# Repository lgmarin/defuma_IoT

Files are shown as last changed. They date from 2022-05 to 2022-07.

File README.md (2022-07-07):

# Defuma IoT

## _An ESP8266 based smoker controller and data acquisition system. AKA: Defumadeira Controle Remoto_

[]()


<p align="center">
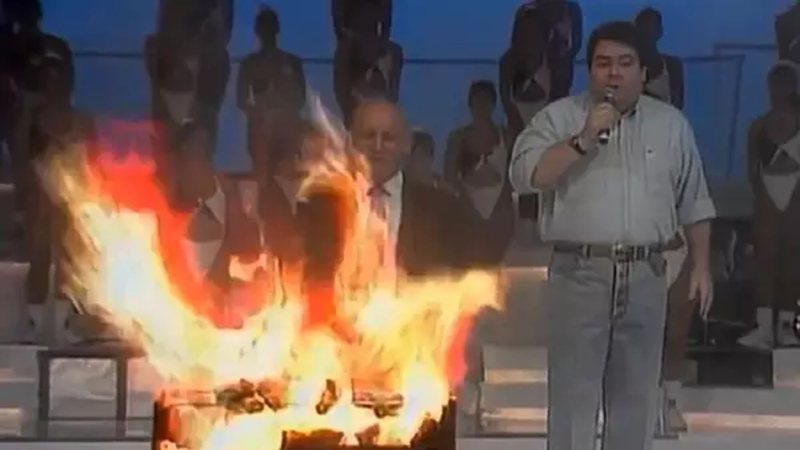
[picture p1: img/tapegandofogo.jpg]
Tá pegando fogo BIXO!!!!
  
</p>

This project was developed with the intention to help to produce a delicious, tender and with an amazing smoked flavored meat! What better way than to make a Nerd happy than with some long smoking process with some friends, some beer and some technology involved, why not?

To acquire a good quality smoked meat, the amount of smoke produced, and mainly the temperature should be constantly controlled (temperature should not be too low and specially, not too high) during the long 12 hours (or more, depending on the cut) to succeed.

The idea here is to have a controller that will display the smoker temperature with a buzzer to signalize the low and high temperature drops. The base system will be developed using an ESP8266 board, that allows for a Wifi Access Point connection that will expose a Web Server that will also display the temperature and allow to define the temperature thresholds.

## Objectives

Development of a data monitoring for a meat smoker:

* Inclusion of a Display and Buzzer to notify the user
* Allow for WiFi connection to visualize the data using a smartphone
* Simple construction and low power
* Future upgrades may include a servo to control the air intake (thus, controlling the smoker temperature)

## Peripherals

* NodeMCU V1.2 ESP8266 Development Board
    * The final project will be built using a ESP12F board.
* MAX6675 Type K Thermocouple Module
* TM1637 4 Digit 8 Segment Display
* Passive Buzzer

## Schematics and List of Materials

<p align="center">
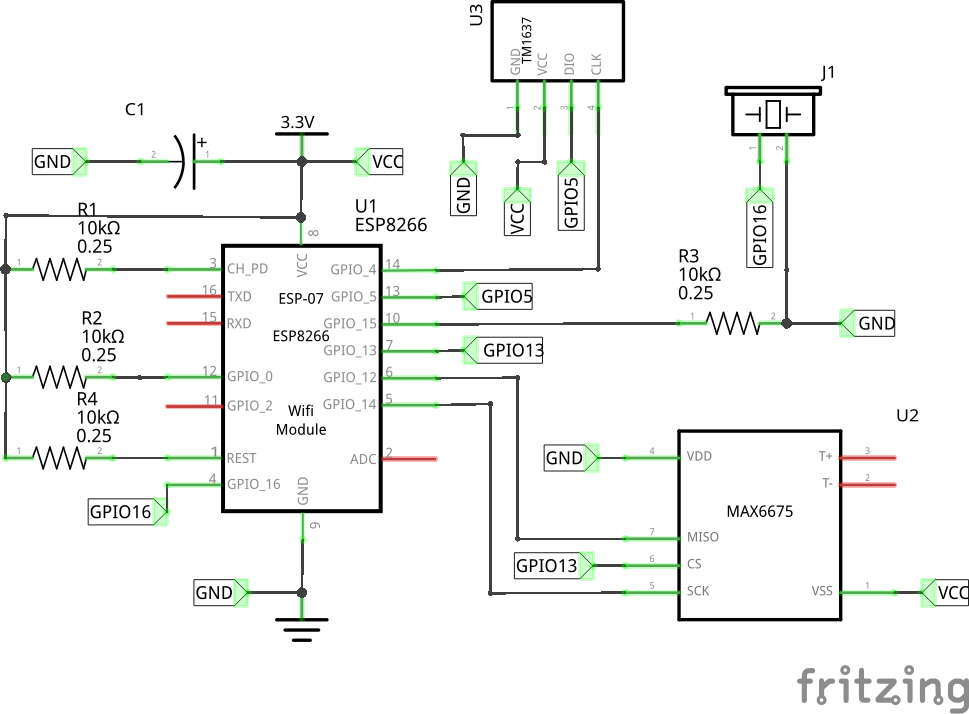
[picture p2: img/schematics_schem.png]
Schematics
  
</p>

| Label | Part Type | Properties |
|-----|-----|---|
|C1|Capacitor Polarized|Electrolytic 10uf 25v|
|J1|Piezo Speaker|-|
|R1-R4|10kΩ Resistor|Tolerance ±5%, Resistance 10kΩ|
|U1|ESP8266 WiFi Module|ESP12F|
|U2|MAX6675|Chip MAX6675; Interface SPI|
|U3|TM1637|4-digit 8-segment Display and Driver|

## Material Design FrontEnd

<p align="center">
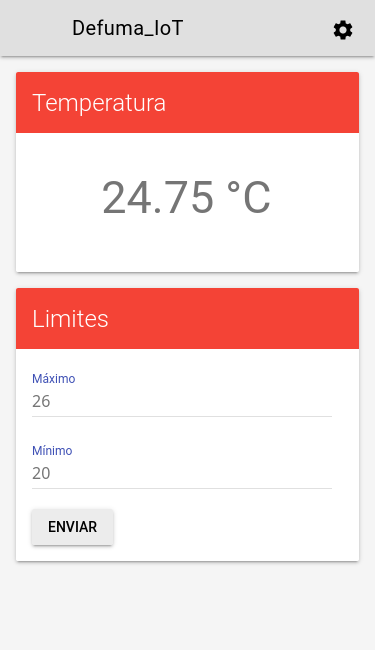
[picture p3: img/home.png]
Home Screen
  
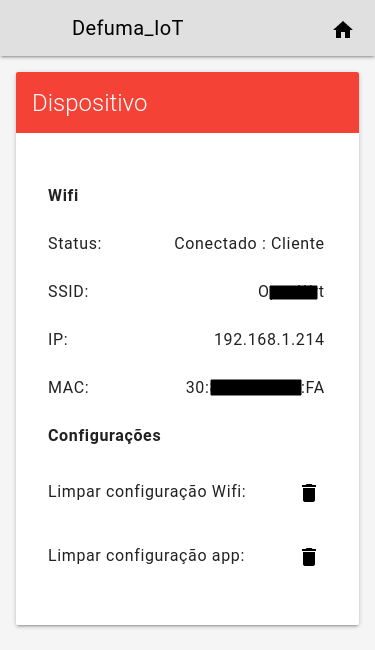
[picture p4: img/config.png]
Config Screen
  
</p>

## Libraries

* SPI (Arduino IDE Default Libraries) - For reading the MAX6675 data through the SPI Bus.
* TM1637 by Smougenot - For displaying data in the display.
* [ESPAsyncTCP](https://github.com/me-no-dev/ESPAsyncTCP) - Base library for ESPAsyncWebServer.
* [ESPAsyncWebServer](https://github.com/me-no-dev/ESPAsyncWebServer) - An Async Web Server implementation for the ESP8266.
* [ESPAsync_WiFiManager](https://github.com/khoih-prog/ESPAsync_WiFiManager) - An Async Wifi Manager to setup the Wifi Information.

## References

* [NodeMCU and ESP pinout and Setup](https://www.mischianti.org/2021/05/08/esp12-esp07-esp8266-flash-pinout-specs-and-arduino-ide-configuration-6/)
* [TM1637 Connection](https://www.electroniclinic.com/tm1637-a-4-digit-7-segment-display-with-arduino/)
* [Read MAX6675 with the SPI Library](https://arduinodiy.wordpress.com/2019/12/06/using-a-max6675-temperature-sensor-without-a-library/)
* [Buzzer with NodeMCU](https://www.geekering.com/categories/embedded-sytems/esp8266/ricardocarreira/esp8266-nodemcu-make-some-noise-with-buzzers/)
* [Control Threshold with an webserver](https://microcontrollerslab.com/esp32-esp8266-thermostat-web-server-control-output-temperature-threshold/)
* [Wifi Manager - Configure Wifi Connection](https://randomnerdtutorials.com/wifimanager-with-esp8266-autoconnect-custom-parameter-and-manage-your-ssid-and-password/)
* [Async WifiManager - AsyncWebServer](https://randomnerdtutorials.com/esp8266-nodemcu-wi-fi-manager-asyncwebserver/)
* [Async WifiManager - AsyncWebServer](https://microcontrollerslab.com/esp32-wi-fi-manager-asyncwebserver/)
* [Async WifiManager](https://stonez56.blogspot.com/2021/07/asyncwifimanager-elegantota-esp8266.html)
* [Plot Sensor Data](https://randomnerdtutorials.com/esp32-esp8266-plot-chart-web-server/)
* [Material Desing Lite Pages](https://www.luisllamas.es/material-design-esp8266/)
* [Scan WIFI](https://www.engineersgarage.com/esp8266-post-data-to-thingspeak-server/)
* [AutoConnect](https://github.com/ayushsharma82/ESPConnect/blob/main/examples/AutoConnect/AutoConnect.ino)
* [Material Design Cards](https://stackoverflow.com/questions/46586217/how-can-i-create-a-mdl-lite-card-like-this-one-with-a-divider-in-between)

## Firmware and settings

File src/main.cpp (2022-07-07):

#include <LittleFS.h>
#include <ESPAsyncWebServer.h>
#include <ESPAsync_WiFiManager.h>
#include <ESP8266mDNS.h>
#include <SPI.h>
#include <TM1637Display.h>

#include "wifi_mgr.h"
#include "read_temp.h"
#include "file_utils.h"

// USING GPIO PINS FOR ESP12 Compatibility!
// D# Pins correspond to nodeMCU V1.2 pins
// TM1637 4d Display Pins
// SCLK -> D2 - GPIO4
// DIO  -> D1 - GPIO5
int tm_DIO = 5;
int tm_CLK = 4;

TM1637Display display(tm_CLK, tm_DIO);

// Define main pins for MAX6675
// SCLK -> D5 - GPIO14
// MISO -> D6 - GPIO12
// CS   -> D7 - GPIO13
int max_CS = 13;
int temperature = 0;

// Buzzer PIN
// BUZZ -> D0 - GPIO16
int BUZZ = 16;

String temp_low = "20";
String temp_high = "26";
String last_temperature;

void notFound(AsyncWebServerRequest *request) {
  request->send(404, "text/plain", "Not found");
}

const char* hostname = "defumaiot";
// Open WebServer connection at PORT 80
AsyncWebServer server(80);
DNSServer dnsServer;

// String processor to be used to parse data to the web browser
String processor(const String& var){
  if(var == "TEMPERATURE"){
    return last_temperature;
  }
  else if(var == "THRESHOLD_MAX"){
    return temp_high;
  }
  else if(var == "THRESHOLD_MIN"){
    return temp_low;
  }
  else if(var == "DEVICE_IP"){
    return WiFi.localIP().toString();
  }
  return String();
}

String config_processor(const String& var){
  if(var == "MODE"){
    switch (WiFi.getMode())
    {
    case WIFI_STA:
      return "Conectado : Cliente";
      break;
    case WIFI_AP:
      return "Conectado : AP";
      break;
    case WIFI_AP_STA:
      return "Conectado : AP + Cliente";
      break;          
    default:
      return "";
      break;
    }
  }
  else if(var == "SSID"){
    return WiFi.SSID();
  }
    else if(var == "HOSTNAME"){
    return hostname;
  }
  else if(var == "DEVICE_IP"){
    return WiFi.localIP().toString();
  }
  else if (var == "MAC")
  {
    return WiFi.macAddress();
  }
  return String();
}

// Configure time interval between readings - 1 second
unsigned long previousMillis = 0;
const long interval = 1000;

void setup(){
  Serial.begin(9600);
  delay(1000);

 //Intiate SPI transaction
  SPI.begin();

  // Init LittleFS
  initFS();

  // Prepare Display and Wait for MAX initialization
  uint8_t data[] = { 0xff, 0xff, 0xff, 0xff };
  display.setBrightness(0x0f);
  display.setSegments(data);

  //Set max_CS Pin as OUTPUT and set to HIGH to Intiate MAX 6675
  pinMode(max_CS, OUTPUT);
  digitalWrite(max_CS, HIGH);

  // Set Buzzer PIN as Output
  pinMode(BUZZ, OUTPUT);

 // AsynWifiManager Block BEGIN

  ESPAsync_WiFiManager ESPAsync_wifiManager(&server, &dnsServer, hostname);
  
  Serial.print("\n[INFO]: Verify if there is some saved credentials...");
  bool initialConfig = false;
  bool configDataLoaded = false;

  if (loadWifiCred())
  {
      configDataLoaded = true;
      ESPAsync_wifiManager.setConfigPortalTimeout(30);
      Serial.print(F("\n[INFO]:Got stored Credentials. Timeout 30s for Config Portal"));
  }
  else
  {
      // Enter CP only if no stored SSID on flash and file 
      Serial.print(F("\n[INFO]:Open Config Portal without Timeout: No stored Credentials."));
      initialConfig = true;
  }

  Serial.print("\n[INFO]:Starting configuration portal @ "); Serial.print("192.168.4.1");

  digitalWrite(LED_BUILTIN, LOW); // turn the LED on by making the voltage LOW to tell us we are in configuration mode.

  // Starts an access point
  if (!ESPAsync_wifiManager.startConfigPortal(hostname)) //(const char *) ssid.c_str())
    Serial.print(F("\n[INFO]: Configuration portal time out. No Wifi Connected..."));
  else
  {
    Serial.print(F("\n[INFO]: WiFi connected!"));
  }  

  if (WiFi.status() == WL_CONNECTED)
  {
    Serial.print(F("\n[INFO]: Connected. Local IP: ")); Serial.print(WiFi.localIP());
  } else
  {
    Serial.print(F("\n[ERROR]: WiFi not connected, with status: ")); Serial.print(ESPAsync_wifiManager.getStatus(WiFi.status()));
    ESPAsync_wifiManager.startConfigPortal(hostname); //(const char *) ssid.c_str())
  }

  // Only clear then save data if CP entered and with new valid Credentials
  if (String(ESPAsync_wifiManager.getSSID(0)) != "" && String(ESPAsync_wifiManager.getPW(0)) != "")
  {
    Serial.print(F("\n[INFO]: WiFi connected! Saving config..."));
    String SSID = ESPAsync_wifiManager.getSSID(0);
    String PW = ESPAsync_wifiManager.getPW(0);
    storeWifiCred(SSID, PW);   // Store data in struct      
    initialConfig = true;
  }

  digitalWrite(LED_BUILTIN, HIGH); // Turn led off as we are not in configuration mode.

  if (!initialConfig)
  {
    // Load stored data, the addAP ready for MultiWiFi reconnection
    if (!configDataLoaded)
      loadWifiCred();
    if ( WiFi.status() != WL_CONNECTED ) 
    {
      Serial.print(F("\n[INFO]: MultiWiFi Configuration..."));
      connectMultiWifi();
    }
  }

  if(loadThresholdConfig()) { //Load Initial configuration data
    temp_low = String(APP_config.temp_min);
    temp_high = String(APP_config.temp_max);
  }

  // AsynWifiManager Block END

  display.clear();

  // Configure Server Async calls
  server.serveStatic("/", LittleFS, "/");

  server.on("/", HTTP_GET, [](AsyncWebServerRequest *request){
    request->send(LittleFS, "/index.html", "text/html", false, processor);
  });

  server.on("/config", HTTP_GET, [](AsyncWebServerRequest *request){
    request->send(LittleFS, "/config.html", "text/html", false, config_processor);
  });

  server.on("/delete-config", HTTP_GET, [](AsyncWebServerRequest *request){
    if(removeThresholdConfig())
      request->send_P(200, "text/plain", "success");
    request->send_P(400, "text/plain", "error");
  });

  server.on("/delete-wifi", HTTP_GET, [](AsyncWebServerRequest *request){
    if(removeWifiCred())
      request->send_P(200, "text/plain", "success");
    request->send_P(400, "text/plain", "error");
  });

  server.on("/update", HTTP_GET, [] (AsyncWebServerRequest *request) {
    if (request->hasParam("threshold_max") && request->hasParam("threshold_min")) {
      temp_high = request->getParam("threshold_max")->value();
      temp_low = request->getParam("threshold_min")->value();
    }

    Serial.print("\n[INFO]: Set threshold_max:");
    Serial.print(temp_high);
    Serial.print("\n[INFO]: Set threshold_min:");
    Serial.print(temp_low);

    storeThresholdConfig(temp_high, temp_low);

    request->send(200, "text/html", "HTTP GET request sent to your ESP.<br><a href=\"/\">Return to Home Page</a>");
  });

  server.on("/temperature", HTTP_GET, [](AsyncWebServerRequest *request){
    request->send_P(200, "text/plain", String(temperature).c_str());
  });

  server.onNotFound(notFound);
  server.begin();

  if (!MDNS.begin(hostname)) {
    Serial.print(F("\n[ERROR]: MultiWiFi Configuration..."));
  }
  // Add Web Server service to mDNS
  MDNS.addService("http", "tcp", 80);
  Serial.print(F("\n[INFO]: mDNS service started. Go to http://defumaiot.local"));
}

void loop(){
  // Use millis() to generate a counter and ditch delay()
  unsigned long currentMillis = millis();
  if (currentMillis - previousMillis >= interval) {
    previousMillis = currentMillis;

    //Read Temperature Data
    temperature = readTemperatureC(max_CS);

    if (temperature == NAN)
    {
      Serial.print(F("Error: No Thermocouple connected!"));
    } 
    else
    {
      display.showNumberDec(temperature);
    }

    // Keep track of the last temperature read
    last_temperature = String(temperature);
    
    if(temperature > temp_high.toInt() && temperature != NAN){
      tone(BUZZ, 523, 800);
    }
    else if(temperature < temp_low.toInt() && temperature != NAN){
      tone(BUZZ, 1000, 200);
    }
    else {
      noTone(BUZZ);
    }
  }

  MDNS.update();
}

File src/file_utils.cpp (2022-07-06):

#include "wifi_mgr.h"
#include <LittleFS.h>
#include <ESP8266WiFiMulti.h>

ESP8266WiFiMulti wifiMulti;

WM_Config         WM_config;
APP_Config        APP_config;

const char* wifi_config_file = "/wifi_cfg.dat";
const char* config_file = "/config.dat";

// Initialize LittleFS
void initFS() {
  if (!LittleFS.begin()) {
    Serial.print(F("\n[ERROR]: An error has occurred while mounting LittleFS"));
  }
  else{
    Serial.print(F("\n[INFO]: LittleFS mounted successfully"));
  }
}

int calcChecksum(uint8_t* address, uint16_t sizeToCalc)
{
  uint16_t checkSum = 0;

  for (uint16_t index = 0; index < sizeToCalc; index++)
  {
    checkSum += * ( ( (byte*) address ) + index);
  }
  return checkSum;
}

bool loadConfigData(void *str_Config, size_t size, char* filename)
{
  File file = LittleFS.open(filename, "r");
  memset(str_Config, 0, size);

  if (file)
  {
    file.readBytes((char *) str_Config, size);
    file.close();
    return true;
  }
  else
  {
    return false;
  }
}

bool saveConfigData(void *str_Config, size_t size, char* filename)
{
  File file = LittleFS.open(filename, "w");

  if (file)
  {
    file.write((uint8_t*) str_Config, size);
    file.close();
    return true;
  }
  else
  {
    return false;
  }
}

bool removeConfigData(char* filename)
{
  if (LittleFS.exists(filename))
  {
    if (LittleFS.remove(filename))
    {
      Serial.print(F("\n[INFO]: File removed!"));
      return true;
    }
    Serial.print(F("[ERROR]: File couldn't be removed! Removal error."));
    return false;
  }
  Serial.print(F("[ERROR]: File couldn't be removed! Not found."));
  return false;
}

bool storeWifiCred(String SSID, String password)
{
  memset(&WM_config, 0, sizeof(WM_config));

 
  for (uint8_t i = 0; i < NUM_WIFI_CREDENTIALS; i++)
  {
    String tempSSID = SSID;
    String tempPW   = password;

    if (strlen(tempSSID.c_str()) < sizeof(WM_config.WiFi_Creds[i].wifi_ssid) - 1)
      strcpy(WM_config.WiFi_Creds[i].wifi_ssid, tempSSID.c_str());
    else
      strncpy(WM_config.WiFi_Creds[i].wifi_ssid, tempSSID.c_str(), sizeof(WM_config.WiFi_Creds[i].wifi_ssid) - 1);

    if (strlen(tempPW.c_str()) < sizeof(WM_config.WiFi_Creds[i].wifi_pw) - 1)
      strcpy(WM_config.WiFi_Creds[i].wifi_pw, tempPW.c_str());
    else
      strncpy(WM_config.WiFi_Creds[i].wifi_pw, tempPW.c_str(), sizeof(WM_config.WiFi_Creds[i].wifi_pw) - 1);  

    // Don't permit NULL SSID and password len < MIN_AP_PASSWORD_SIZE (8)
    if ((String(WM_config.WiFi_Creds[i].wifi_ssid) = "") && (String(WM_config.WiFi_Creds[i].wifi_pw) = ""))
      Serial.println(F("[ERROR]: Null SID or Password!"));

  }
  //Calculate checksum and save credentials
  WM_config.checksum = calcChecksum((uint8_t*) &WM_config, sizeof(WM_config) - sizeof(WM_config.checksum));
  if (saveConfigData(&WM_config, sizeof(WM_config), (char*) wifi_config_file))
  {
    Serial.print(F("\n[INFO]: Wifi Credentials file saved!"));
    return true;
  }

  Serial.print(F("\n[ERROR]: Could not store Wifi Config File"));
  return false;
}

bool loadWifiCred()
{
  if(loadConfigData(&WM_config, sizeof(WM_config), (char*) wifi_config_file))
  {
    if ( WM_config.checksum != calcChecksum( (uint8_t*) &WM_config, sizeof(WM_config) - sizeof(WM_config.checksum) ) )
    {
      Serial.print(F("\n[ERROR]: Wifi Credentials checksum wrong!"));
      return false;
    }
    for (uint8_t i = 0; i < NUM_WIFI_CREDENTIALS; i++)
    {
      // Don't permit NULL SSID and password len < MIN_AP_PASSWORD_SIZE (8)
      if ( (String(WM_config.WiFi_Creds[i].wifi_ssid) != "") && (String(WM_config.WiFi_Creds[i].wifi_pw) != "") )
      {
        wifiMulti.addAP(WM_config.WiFi_Creds[i].wifi_ssid, WM_config.WiFi_Creds[i].wifi_pw);
      }
    }
    return true;
    Serial.print(F("\n[INFO]: Wifi Config File Read. Checksum ok."));
  }
  else
  {
    Serial.print(F("\n[ERROR]: Could not read Wifi Config File."));
    return false;
  }
}

void connectMultiWifi()
{
  #define WIFI_MULTI_1ST_CONNECT_WAITING_MS             2200L
  #define WIFI_MULTI_CONNECT_WAITING_MS                  500L

  uint8_t status;

  Serial.print(F("\n[INFO]: Connecting MultiWifi..."));

  int i = 0;
  status = wifiMulti.run();
  delay(WIFI_MULTI_1ST_CONNECT_WAITING_MS);

  while ( ( i++ < 20 ) && ( status != WL_CONNECTED ) )
  {
    status = WiFi.status();

    if ( status == WL_CONNECTED )
    break;
    else
    delay(WIFI_MULTI_CONNECT_WAITING_MS);
  }

  if ( status == WL_CONNECTED )
  {
    Serial.print(F("\n[INFO] WiFi connected!"));
    Serial.print(F("\nSSID: ")); Serial.print(WiFi.SSID()); 
    Serial.print(F("\nRSSI= ")); Serial.print(WiFi.RSSI());
    Serial.print(F("\nIP address: ")), Serial.print(WiFi.localIP());
  }
  else
  {
    Serial.println(F("\n[ERROR]: No WiFi connected, reseting ESP!")); 
    ESP.reset();
  }
}

void checkWifiStatus()
{
  static float checkwifi_timeout = 0;
  static float current_millis;

  current_millis = millis();

  if ((WiFi.status() != WL_CONNECTED))
  {
    if ((current_millis > checkwifi_timeout) || (checkwifi_timeout == 0))
    {
      checkwifi_timeout = current_millis + WIFICHECK_INTERVAL;      
      Serial.println(F("\n[ERROR]: WiFi lost. Call connectMultiWiFi in loop"));
      connectMultiWifi();
    } 
  }
}

bool loadThresholdConfig()
{
  if(loadConfigData(&APP_config, sizeof(APP_config), (char*) config_file))
  {
    Serial.print(F("\n[INFO]: App Config File Read."));
    Serial.print(F("\nt_min ")); Serial.print(String(APP_config.temp_min));
    Serial.print(F("\nt_max ")); Serial.print(String(APP_config.temp_max));
    return true;
  }

  Serial.print(F("\n[ERROR]: Could not read App Config File"));
  return false;
}

bool storeThresholdConfig(String t_max, String t_min)
{
  memset(&APP_config, 0, sizeof(APP_config));
  
  if (strlen(t_max.c_str()) < sizeof(APP_config.temp_max) - 1)
    strcpy(APP_config.temp_max, t_max.c_str());
  else
    strncpy(APP_config.temp_max, t_max.c_str(), sizeof(APP_config.temp_max) - 1);

  if (strlen(t_min.c_str()) < sizeof(APP_config.temp_min) - 1)
    strcpy(APP_config.temp_min, t_min.c_str());
  else
    strncpy(APP_config.temp_min, t_min.c_str(), sizeof(APP_config.temp_min) - 1);

  Serial.print(F("\n[INFO]: App Config File Store."));
  Serial.print(F("\nt_min: ")); Serial.print(String(APP_config.temp_min));
  Serial.print(F("\nt_max: ")); Serial.print(String(APP_config.temp_max));


  // Don't permit NULL values
  if (String(APP_config.temp_max) == "")
  {
    Serial.print(F("\n[ERROR]: Invalid null Threshold value."));
    return false;
  }

  if(saveConfigData(&APP_config, sizeof(APP_config), (char*) config_file))
  {
    Serial.print(F("\n[INFO]: APP Configuration saved!"));
    return true;
  }

  Serial.print(F("\n[ERROR]: Could not save APP Configuration."));
  return false;
}

bool removeThresholdConfig()
{
  if(removeConfigData((char*) config_file))
    return true;

  return false;
}

bool removeWifiCred()
{
  if(removeConfigData((char*) wifi_config_file))
    return true;

  return false;
}

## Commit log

2022-05-30 Read Temp Through SPI
2022-05-30 Fix TM1637 Pinout and Brightness
    [main.cpp]
2022-05-30 Connecting buzzer for alerts
    [main.cpp]
2022-05-30 Temperature threshold for buzzer
    [main.cpp]
2022-06-02 Fix some minor bugs
    [main.cpp]
2022-06-07 Refactor - Read Temperature h
2022-06-08 Add Material Lite page
2022-06-08 Fix html request response
    [main.cpp]
2022-06-12 Edit Readme and add schematics
    [schematics.fzz]
2022-06-15 Set timer to update temperature reading
2022-06-16 Correct some minor mistakes
    [main.cpp]
2022-06-16 Correct CSS and corret XHTML time interval
    [main.cpp]
2022-06-17 Roundo sent temperature data
2022-06-19 Update Schematics
    [schematics.fzz]
2022-06-19 Fix PIN GPIO port for ESP12F compatibility
    [schematics.fzz]
2022-06-27 Try fixing linking error
    [file_utils.cpp, main.cpp]
2022-06-28 Fix Linking error, remove interdependencies
    [file_utils.cpp, main.cpp]
2022-06-29 Attempt to fix saving issues
    [file_utils.cpp, main.cpp]
2022-06-29 Fixing timing and filenames
    [file_utils.cpp, main.cpp]
2022-07-03 Fixing app configuration mistakes, intial config page
    [file_utils.cpp, main.cpp]
2022-07-03 Add go To config button at home page
2022-07-03 Write routes, still errors in Config
    [file_utils.cpp, main.cpp]
2022-07-04 Fix config page processor
    [main.cpp]
2022-07-04 Fix JS get calls
    [main.cpp]
2022-07-04 Fix invalid SSID check
    [file_utils.cpp, main.cpp]
2022-07-04 Try to fix request, try to fix wifi cred error
    [file_utils.cpp]
2022-07-05 Finally fix storing credentials, try redirect (not working)
    [main.cpp]
2022-07-06 Fix links and routes
    [file_utils.cpp, main.cpp]
